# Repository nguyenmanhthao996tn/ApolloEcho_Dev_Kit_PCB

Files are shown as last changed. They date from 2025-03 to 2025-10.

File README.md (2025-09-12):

# ApolloEcho Dev Kit

This repository contains the PCB designs, related documents, and source code for the **ApolloEcho Dev Kit**.

The **ApolloEcho Dev Kit** includes two primary components: the **RAKwireless RAK11720** and the **EchoStar Mobile EM2050**. It is designed to provide a rapid and efficient approach to getting started with the EchoStar Mobile satellite network. All pinouts for the two modules are available in standard 2.54mm headers. The antenna is fully customizable via 6 SMA connectors.

## Rev 210 (Version 2.1.0)

### Changelog

- Change EM_RTS from PB12 to PA10
- Change J16 Pin 7 from PA10 to PB12
- Change J17 Pin 4 from PA10 to PB12
- Add 1 MOhm (R3) pull-down resistor for LDO_EM_PWR_EN

| Top View | Bottom View |
| :---: | :---: |
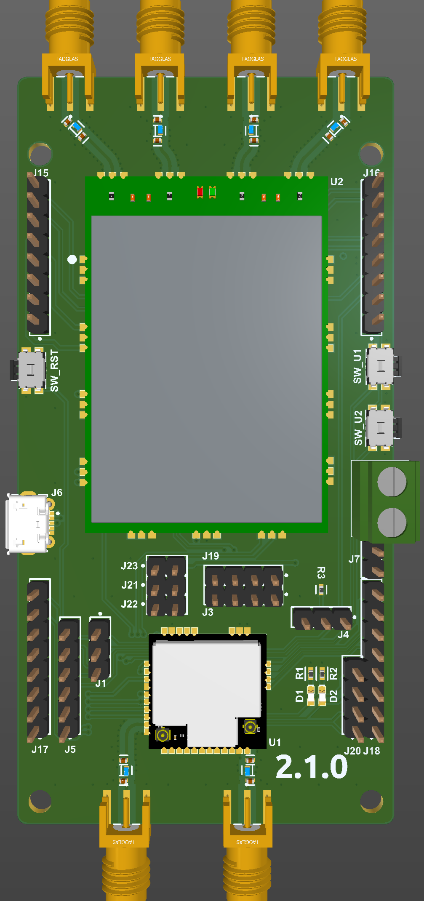
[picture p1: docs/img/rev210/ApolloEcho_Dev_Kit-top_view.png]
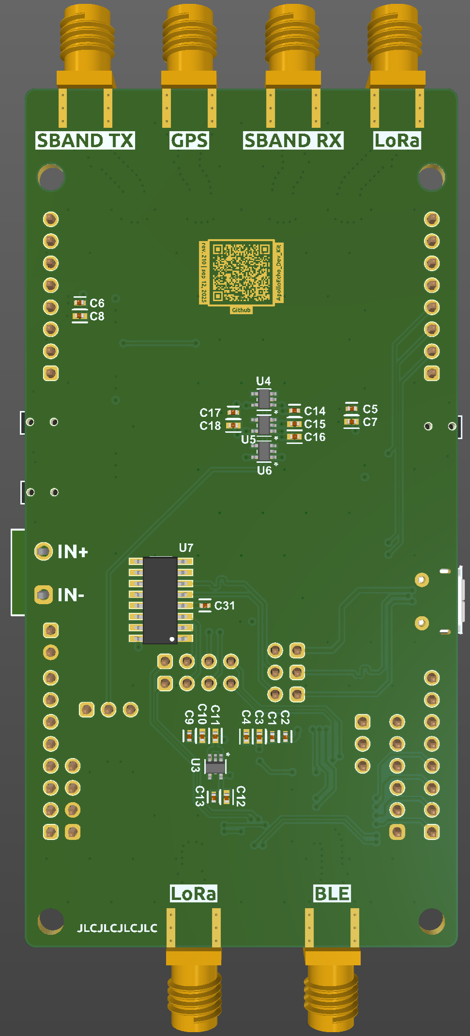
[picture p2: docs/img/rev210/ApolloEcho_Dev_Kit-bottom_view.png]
|  |  |

## Rev 200 (Version 2.0.0)

### Changelog

- Add integrated CH340C USB TTL IC
- Integrated USB TTL IC can interact with both RAK11720 and EM2050

| Top View | Bottom View |
| :---: | :---: |
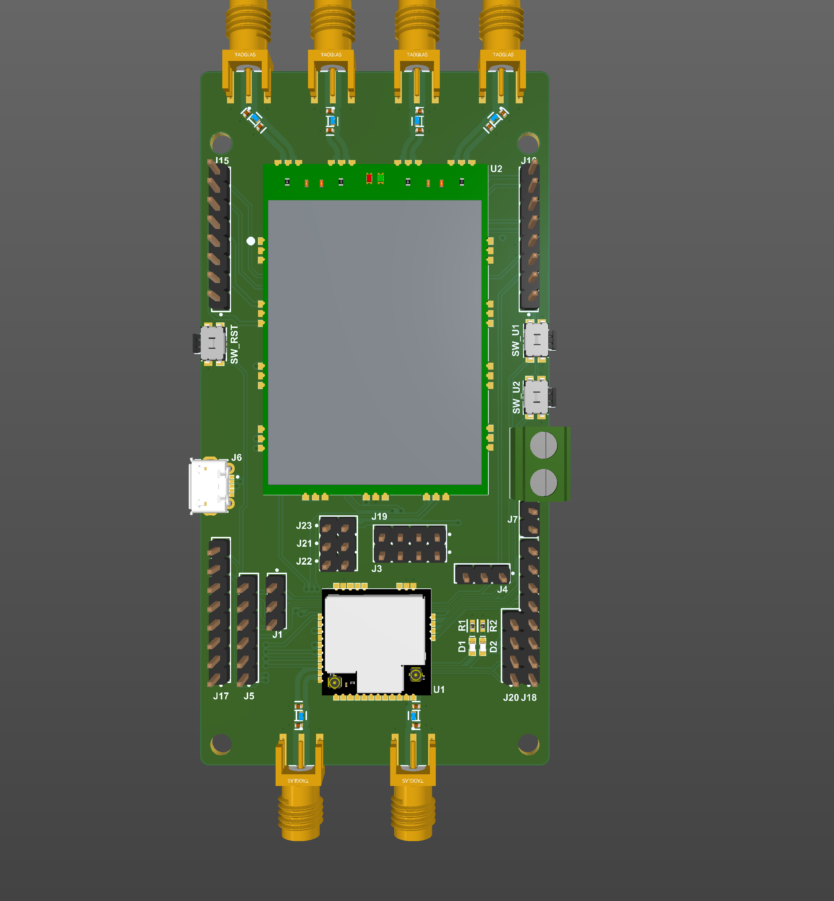
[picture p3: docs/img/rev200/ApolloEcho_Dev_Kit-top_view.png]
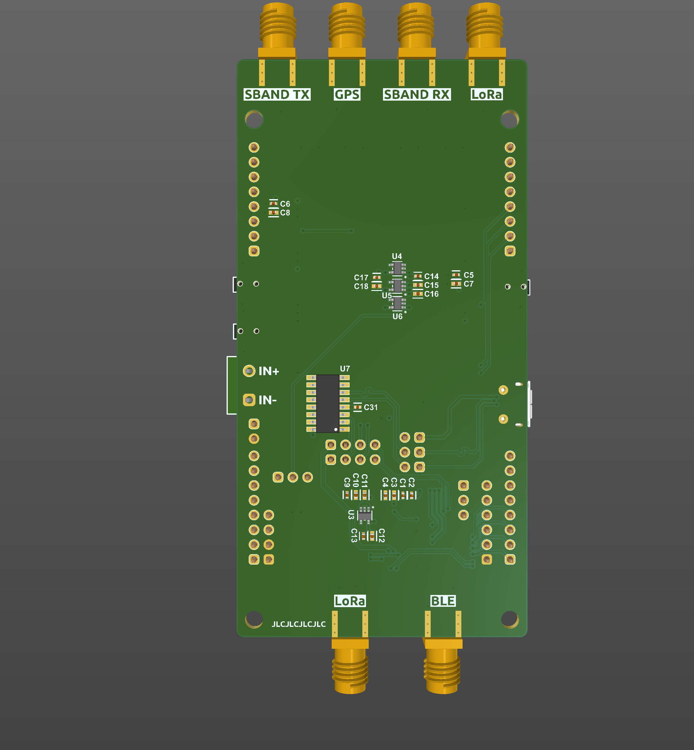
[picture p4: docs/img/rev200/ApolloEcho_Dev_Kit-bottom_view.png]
|  |  |

## Rev 100 (Version 1.0.0)

### Overview

The kit includes a separate CH340C on a USB Serial Daughter Board. For programming and debugging, the USB Serial Daughter Board provides a simple connection via Micro USB. For battery-powered deployments that require low power, removing the USB Serial Daughter Board can improve autonomy.

| Top View | Bottom View |
| :---: | :---: |
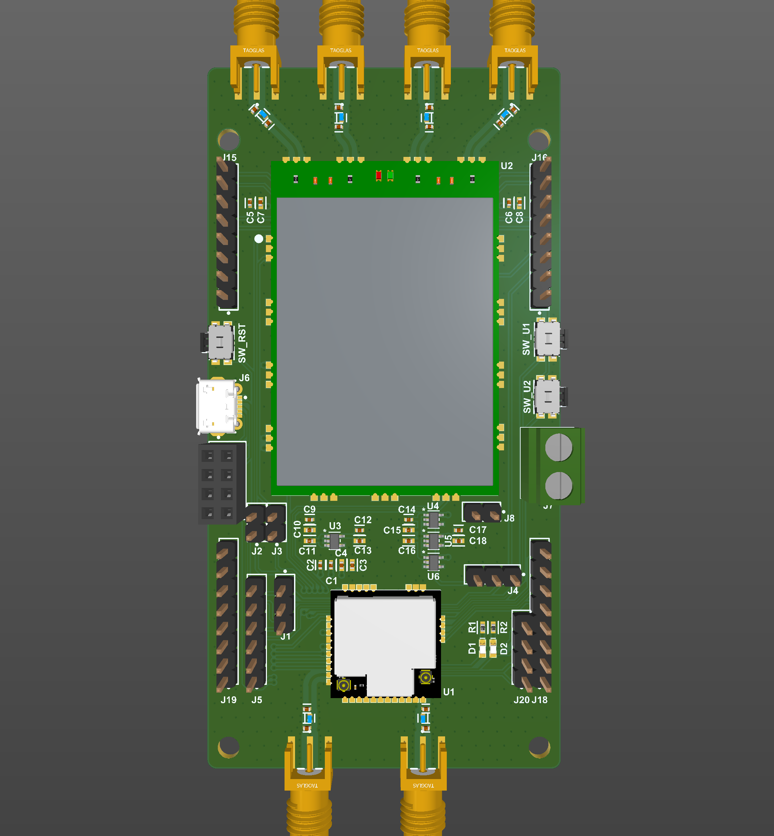
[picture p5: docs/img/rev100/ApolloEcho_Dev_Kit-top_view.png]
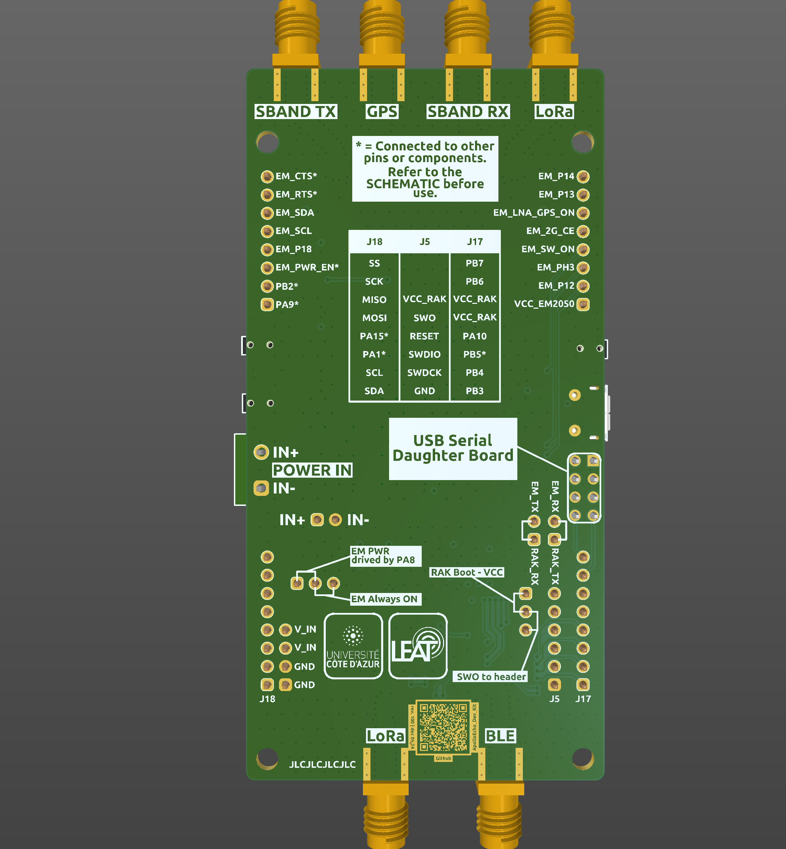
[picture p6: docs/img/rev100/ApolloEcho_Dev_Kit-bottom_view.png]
|  |  |

| Top View | Bottom View |
| :---: | :---: |
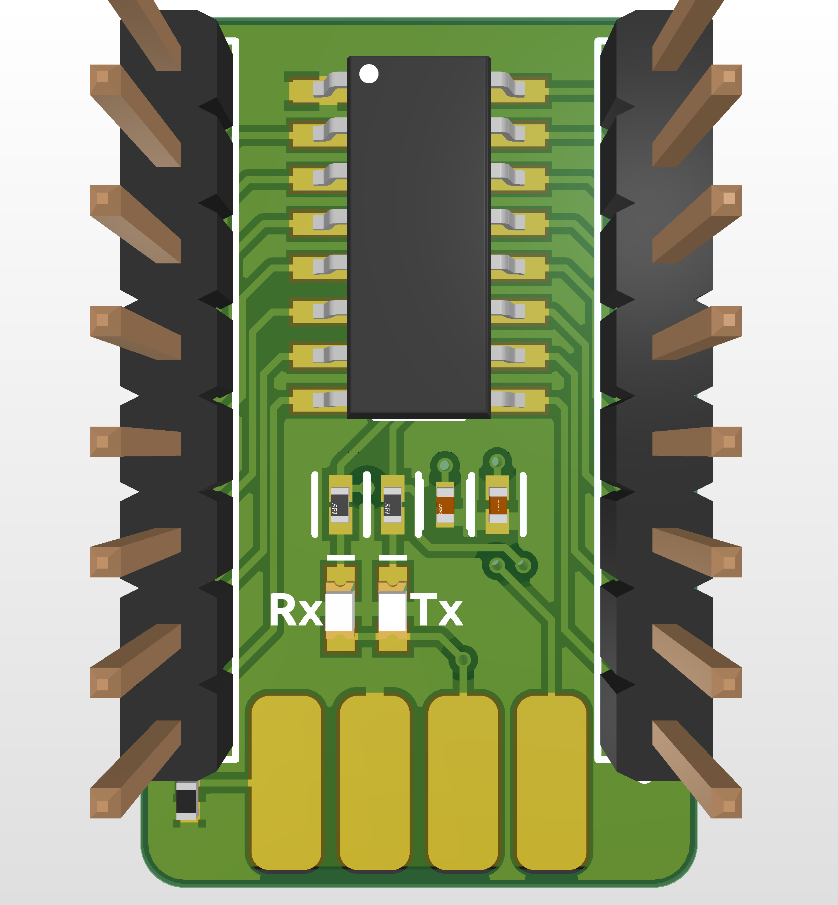
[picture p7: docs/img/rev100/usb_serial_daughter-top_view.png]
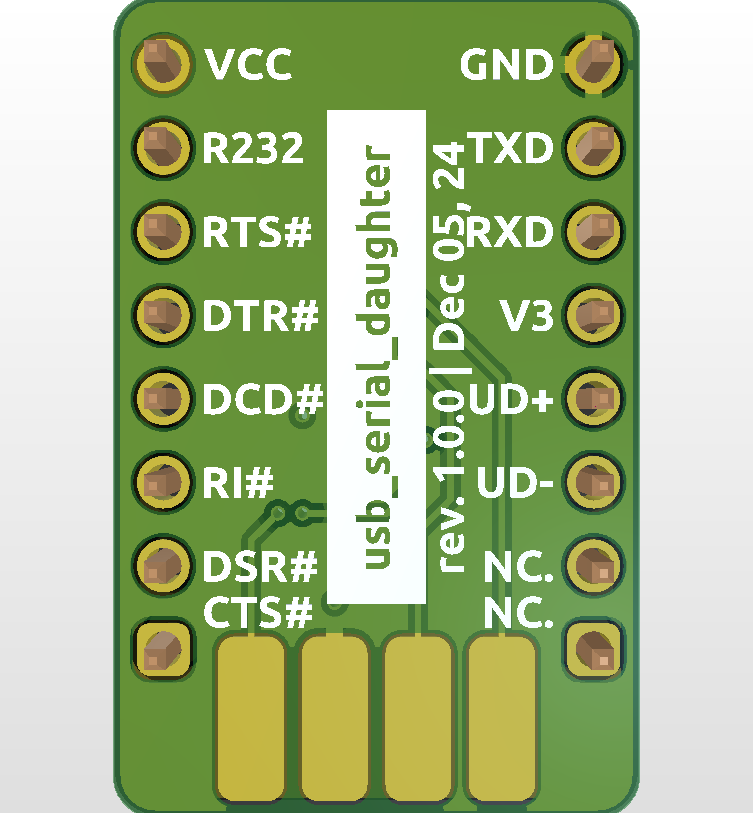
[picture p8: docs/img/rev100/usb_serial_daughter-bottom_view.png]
|  |  |

### Known issues

- The USBSerial Daughter board is not working.
- The SMA connectors are too close to each other.
- The QR code on the bottom is open in the paste layer. It's unscannable on the final board due to the soldering tin.

---

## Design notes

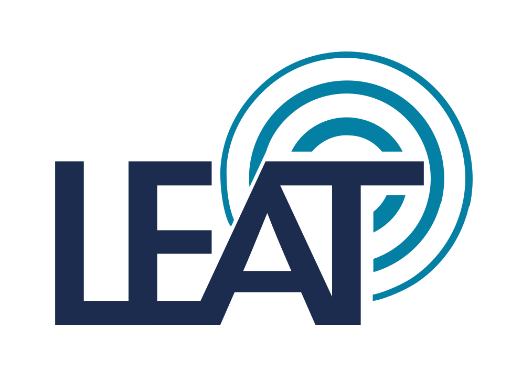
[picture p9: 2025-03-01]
docs/img/new-leat.png

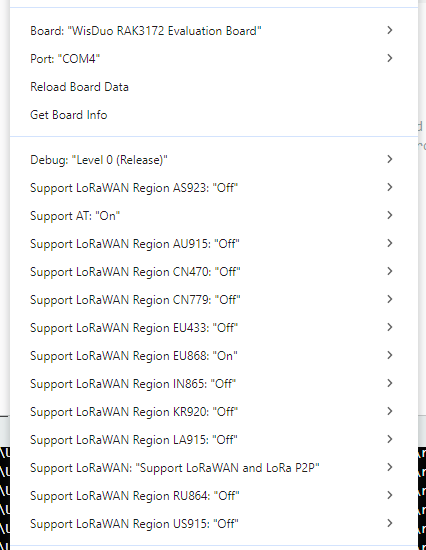
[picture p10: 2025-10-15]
docs/training_docs/arduino_rak3172_menu_config.png

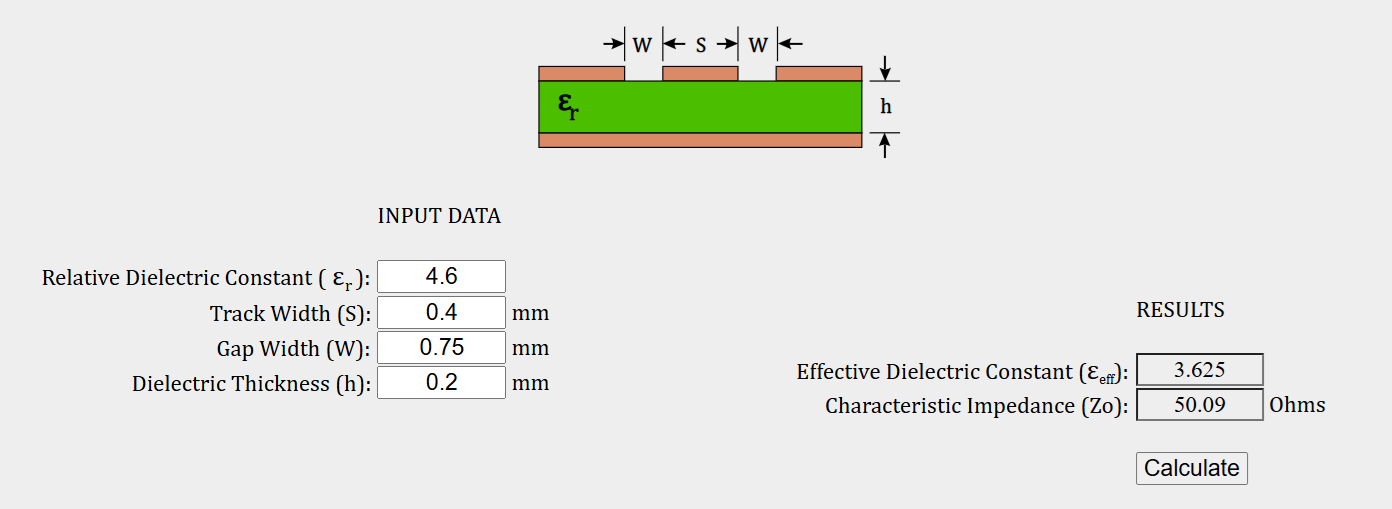
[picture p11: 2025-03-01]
docs/coplanar_matching.png

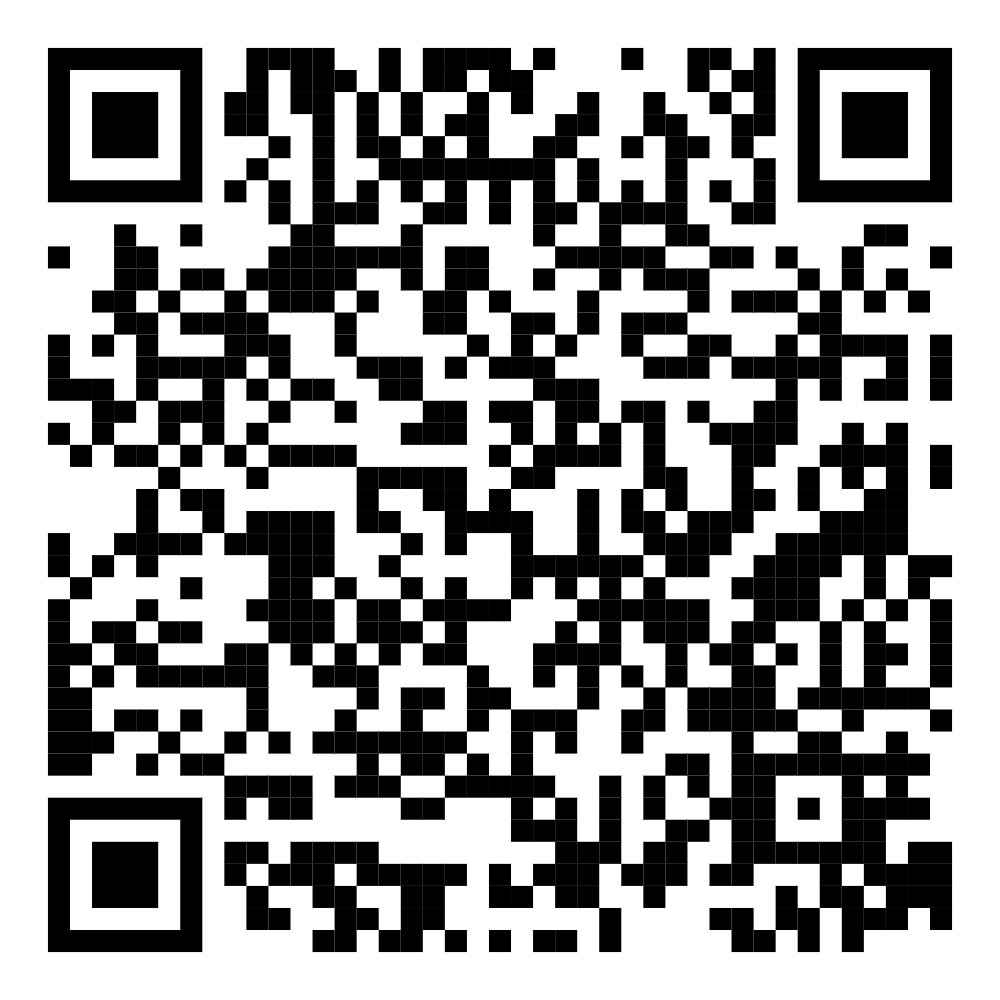
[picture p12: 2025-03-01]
docs/img/github.png

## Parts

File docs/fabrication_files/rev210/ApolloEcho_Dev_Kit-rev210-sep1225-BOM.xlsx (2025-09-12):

Comment | Description | Designator | Footprint | LibRef | Quantity | Value | Manufacture | Manufacturer | Manufacturer Packaging 1 | Manufacturer P/N | Manufacturer Part Number | Manufacturer URL
0402ZD104KAT2A | General Purpose Ceramic Capacitor, 0402, 100nF, 10%, X5R, 15%, 10V | C1, C2, C5, C6, C9, C12, C14, C17, C31 | FP-0402-L_1_0_1-W_0_5_0_1-IPC_C | CMP-2008-02878-3 | 9
EMK105BJ105KV-F | None | C3, C4, C7, C8, C10, C13, C15, C18 | FP-0402-L_1_0_0_05-W_0_5-IPC_A | CMP-14477-000104-2 | 8
C1005X5R1A225K050BC | Multilayer Ceramic Capacitors 2.2μF ±10% 10V X5R SMD 0402 | C11, C16 | FP-C1005-050-0_05-IPC_A | CMP-08246-002709-1 | 2
GJM1555C1H5R0CB01D | Multi-Layer Ceramic Capacitor 5pF C0G ±0.25pF 0402 Paper T/R | C19, C20, C21, C22, C23, C24, C25, C26, C27, C28, C29, C30 | FP-GJM155-0_05-MFG | CMP-2008-03860-2 | 12
150060VS75000 | WURTH ELEKTRONIK - 150060VS75000 - LED, Green, SMD, 0603, 30 mA, 2 V, 570 nm | D1 | WL-SMCW_0603_150060xx75000 | CMP-1426-00006-7 | 1
150060RS75000 | LED Low-Power Uni-Color Red 630nm 2V 2-Pin Chip 0603(1608Metric) T/R | D2 | WL-SMCW_0603_150060xx75000 | CMP-1426-00001-4 | 1
61300311121 |  | J1, J4 | 61300311121 | CMP-1502-01062-3 | 2
61300411121 |  | J3, J19, J20 | 61300411121 | CMP-1502-01064-3 | 3
61300611121 |  | J5 | 61300611121 | CMP-1502-01070-3 | 1
105017-0001 | Micro-USB B Receptacle, Right Angle, Bottom Mount, Surface Mount, with Solder Tabs, -30 to 85 degC, 5-Pin USB, RoHS, Tape and Reel | J6 | USB-MICRO-B_V | CMP-2000-05827-1 | 1 |  |  | Molex |  |  |  | http://www.molex.com/
691137710002 |  | J7 | 691137710002 | CMP-1502-03324-2 | 1
61300211121 |  | J8, J21, J22, J23 | 61300211121 | CMP-1712-00002-6 | 4
EMPCB.SMAFSTJ.B.HT | CONN SMA JACK STR 50OHM EDGE MNT | J9, J10, J11, J12, J13, J14 | FP-EMPCB_SMAFSTJ_B_HT-MFG | CMP-111093-000001-1 | 6 |  |  | Taoglas Limited |  |  | EMPCB.SMAFSTJ.B.HT
61300811121 |  | J15, J16, J17, J18 | 61300811121 | CMP-1502-01076-3 | 4
LQW15AN2N9D00D | Wire Wound RF Inductor 2.9nH ±0.5nH 750mA 0.07Ω 0402 (1005) | L1, L2, L3, L4, L5, L6 | FP-LQW15AN_00-W0_6-0_1-MFG | CMP-06042-011289-1 | 6
RMCF0402FT1K00 | 1kΩ ±1% 0.063W 0402 Thick Film Chip Resistor AEC-Q200 compliant | R1, R2 | FP-RMCF0402-IPC_A | CMP-26527-000026-1 | 2
RMCF0402FT1M00 | 1MΩ ±1% 0.063W 0402 Thick Film Chip Resistor AEC-Q200 compliant | R3 | FP-RMCF0402-MFG | CMP-2000-06985-2 | 1
436333045822 |  | SW_RST, SW_U1, SW_U2 | 436333045822 | CMP-1464-00001-2 | 3
RAK11720 | RAK11720 Ambiq Apollo3 Blue SX1262 LoRa Bluetooth Module for LoRaWAN | U1 | RAK11720 | RAK11720 | 1
IOT SAT module | Echostar Mobile IOT SAT Module - Basic version | U2 | EM2050 | EM2050 | 1 | EM2050 |  | Echostar Mobile Ltd |  | EM2050
STLQ020C33R | No Description Available | U3, U4, U5, U6 | SOT323-5L_STM | STLQ020C33R | 4
CH340C | USB to Serial CH340 IC | U7 | CH340C | CH340C | 1

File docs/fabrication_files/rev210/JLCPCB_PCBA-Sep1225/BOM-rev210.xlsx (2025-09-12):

Comment | Designator | Footprint | JLCPCB Part #（optional）
16V 100nF X7R ±10% 0402 Multilayer Ceramic Capacitors MLCC - SMD/SMT ROHS | C1, C2, C5, C6, C9, C12, C14, C17, C31 | 0402 | C1525
25V 1uF X5R ±10% 0402 Multilayer Ceramic Capacitors MLCC - SMD/SMT ROHS | C3, C4, C7, C8, C10, C13, C15, C18 | 0402 | C52923
6.3V 2.2uF X5R ±20% 0402 Multilayer Ceramic Capacitors MLCC - SMD/SMT ROHS | C11, C16 | 0402 | C12530
-40℃~+85℃ Red 0603 LED Indication - Discrete ROHS | D1 | 0603 | C2286
White 0603 LED Indication - Discrete ROHS | D2 | 0603 | C2290
62.5mW Thick Film Resistors 50V ±1% 0Ω 0402 Chip Resistor - Surface Mount ROHS | L1, L2, L3, L4, L5, L6 | 0402 | C17168
62.5mW Thick Film Resistors 50V ±100ppm/℃ ±1% 1kΩ 0402 Chip Resistor - Surface Mount ROHS | R1, R2 | 0402 | C11702
62.5mW Thick Film Resistors 50V ±100ppm/℃ ±1% 1MΩ 0402 Chip Resistor - Surface Mount ROHS | R3 | 0402 | C26083
3.2mm 2.5mm Oval button 50mA Standing paste 4.2mm SPST 16V SMD Tactile Switches ROHS | SW_RST, SW_U1, SW_U2 | SMD | C115360
LDO Voltage Regulators 200 mA ultra-low quiescent current LDO | U3, U4, U5, U6 | SOT-323-5 | C2970558
SOP-16 USB Converters ROHS | U7 | SOP-16 | C7464026
1 Inner Hole SMA Board-End Staggered pins 50Ω 5.2mm SMD Coaxial Connectors (RF) ROHS | J9, J10, J11, J12, J13, J14 | SMD | C496550
1.8A USB 2.0 1 Horizontal attachment 5P Female -20℃~+85℃ Micro-B SMD USB Connectors ROHS | J6 | SMD | C404969
1x2P -40℃~+105℃ 12A 300V Green 14~26 Direct Insert 5.08mm 1 2 P=5.08mm Screw Terminal Blocks ROHS | J7 | P=5.08mm | C3018698

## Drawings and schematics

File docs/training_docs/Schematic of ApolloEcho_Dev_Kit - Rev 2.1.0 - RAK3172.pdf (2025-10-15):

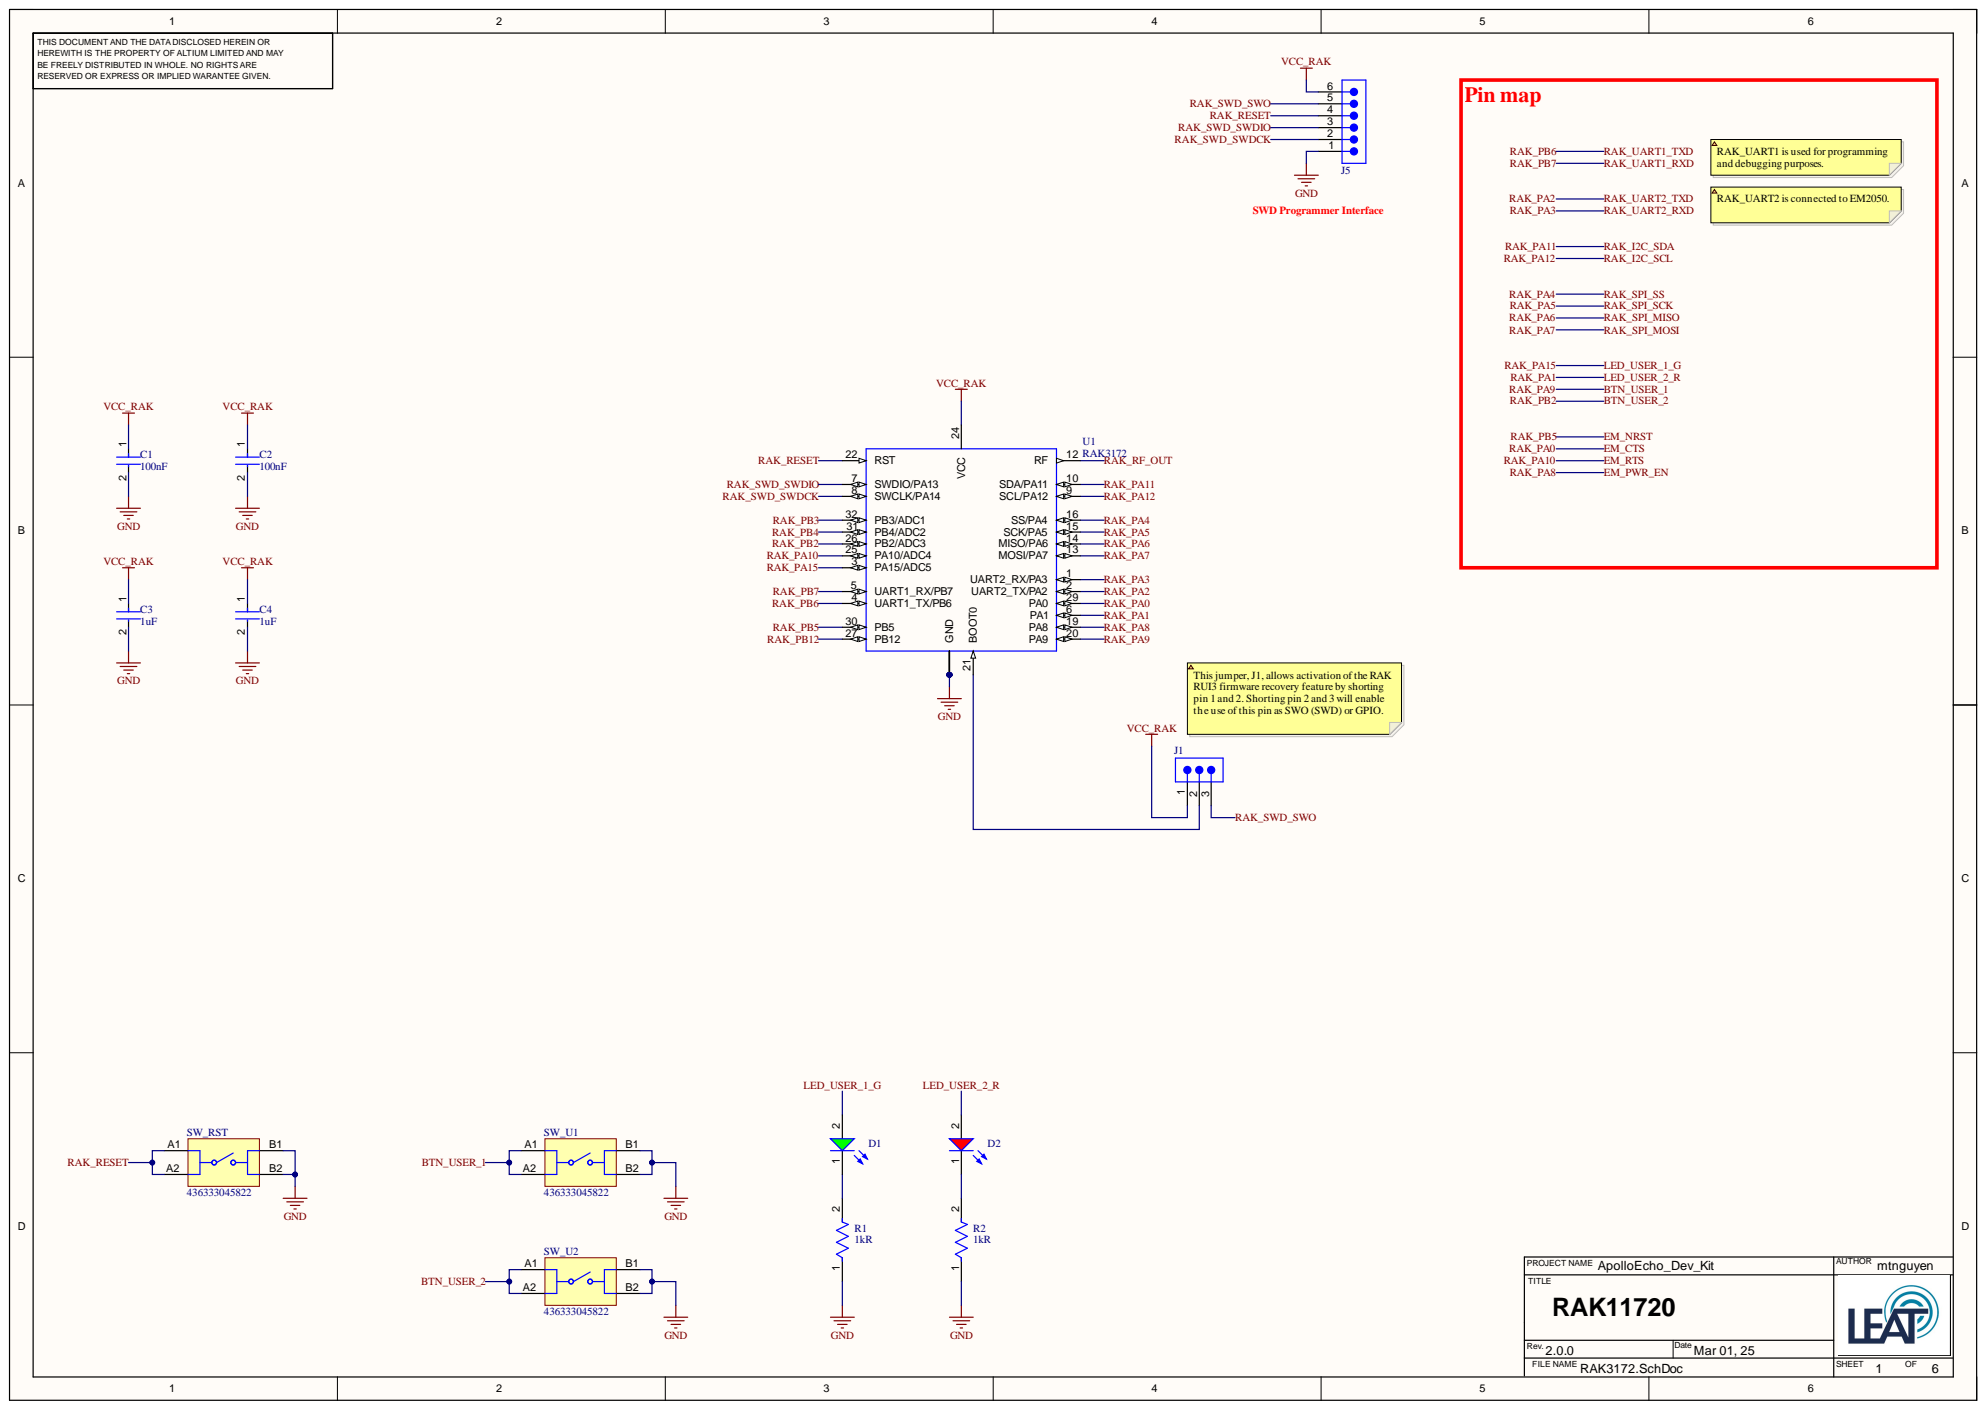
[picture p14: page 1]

THIS DOCUMENT AND THE DATA DISCLOSED HEREIN OR
HEREWITH IS THE PROPERTY OF ALTIUM LIMITED AND MAY
BE FREELY DISTRIBUTED IN WHOLE. NO RIGHTS ARE
RESERVED OR EXPRESS OR IMPLIED WARANTEE GIVEN.

RAK_UART1 is used for programming
and debugging purposes.

This jumper, J1, allows activation of the RAK
RUI3 firmware recovery feature by shorting
pin 1 and 2. Shorting pin 2 and 3 will enable
the use of this pin as SWO (SWD) or GPIO.

Rev. 2.0.0 | Date Mar 01, 25
FILE NAME RAK3172.SchDoc | SHEET OF 1

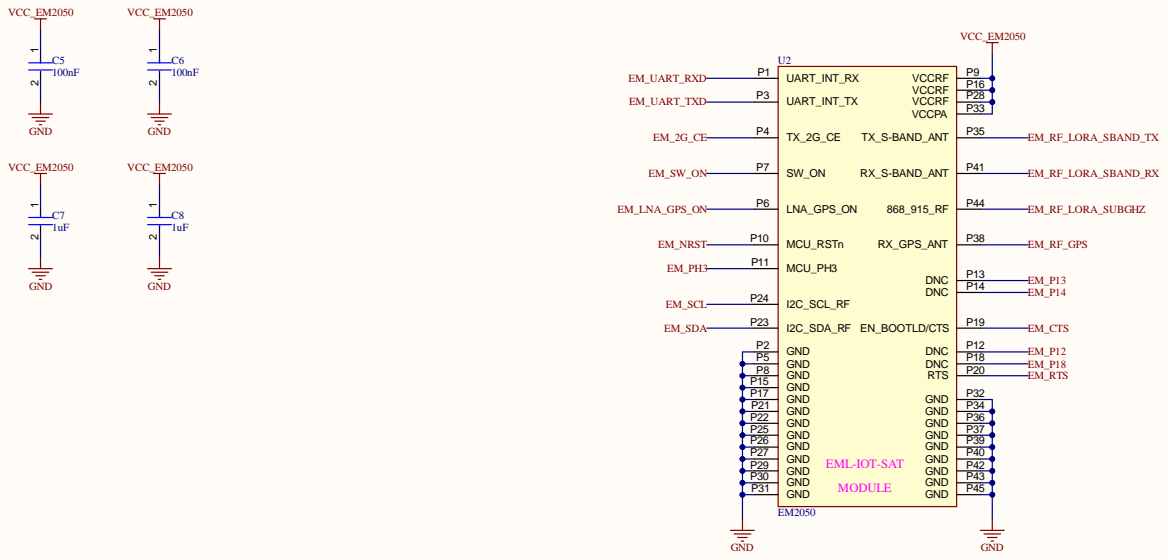
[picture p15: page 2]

AND THE DATA DISCLOS
ENT

PROJECT NA M E | AUTHOR ApolloEcho_Dev_Kit e n
TIT L E EM2050 | T OF mtnguy

Re v . 2.0 . 0 | Date M ar 1,
FIL E NA M E EM 0.Sc h D o c | SHE E

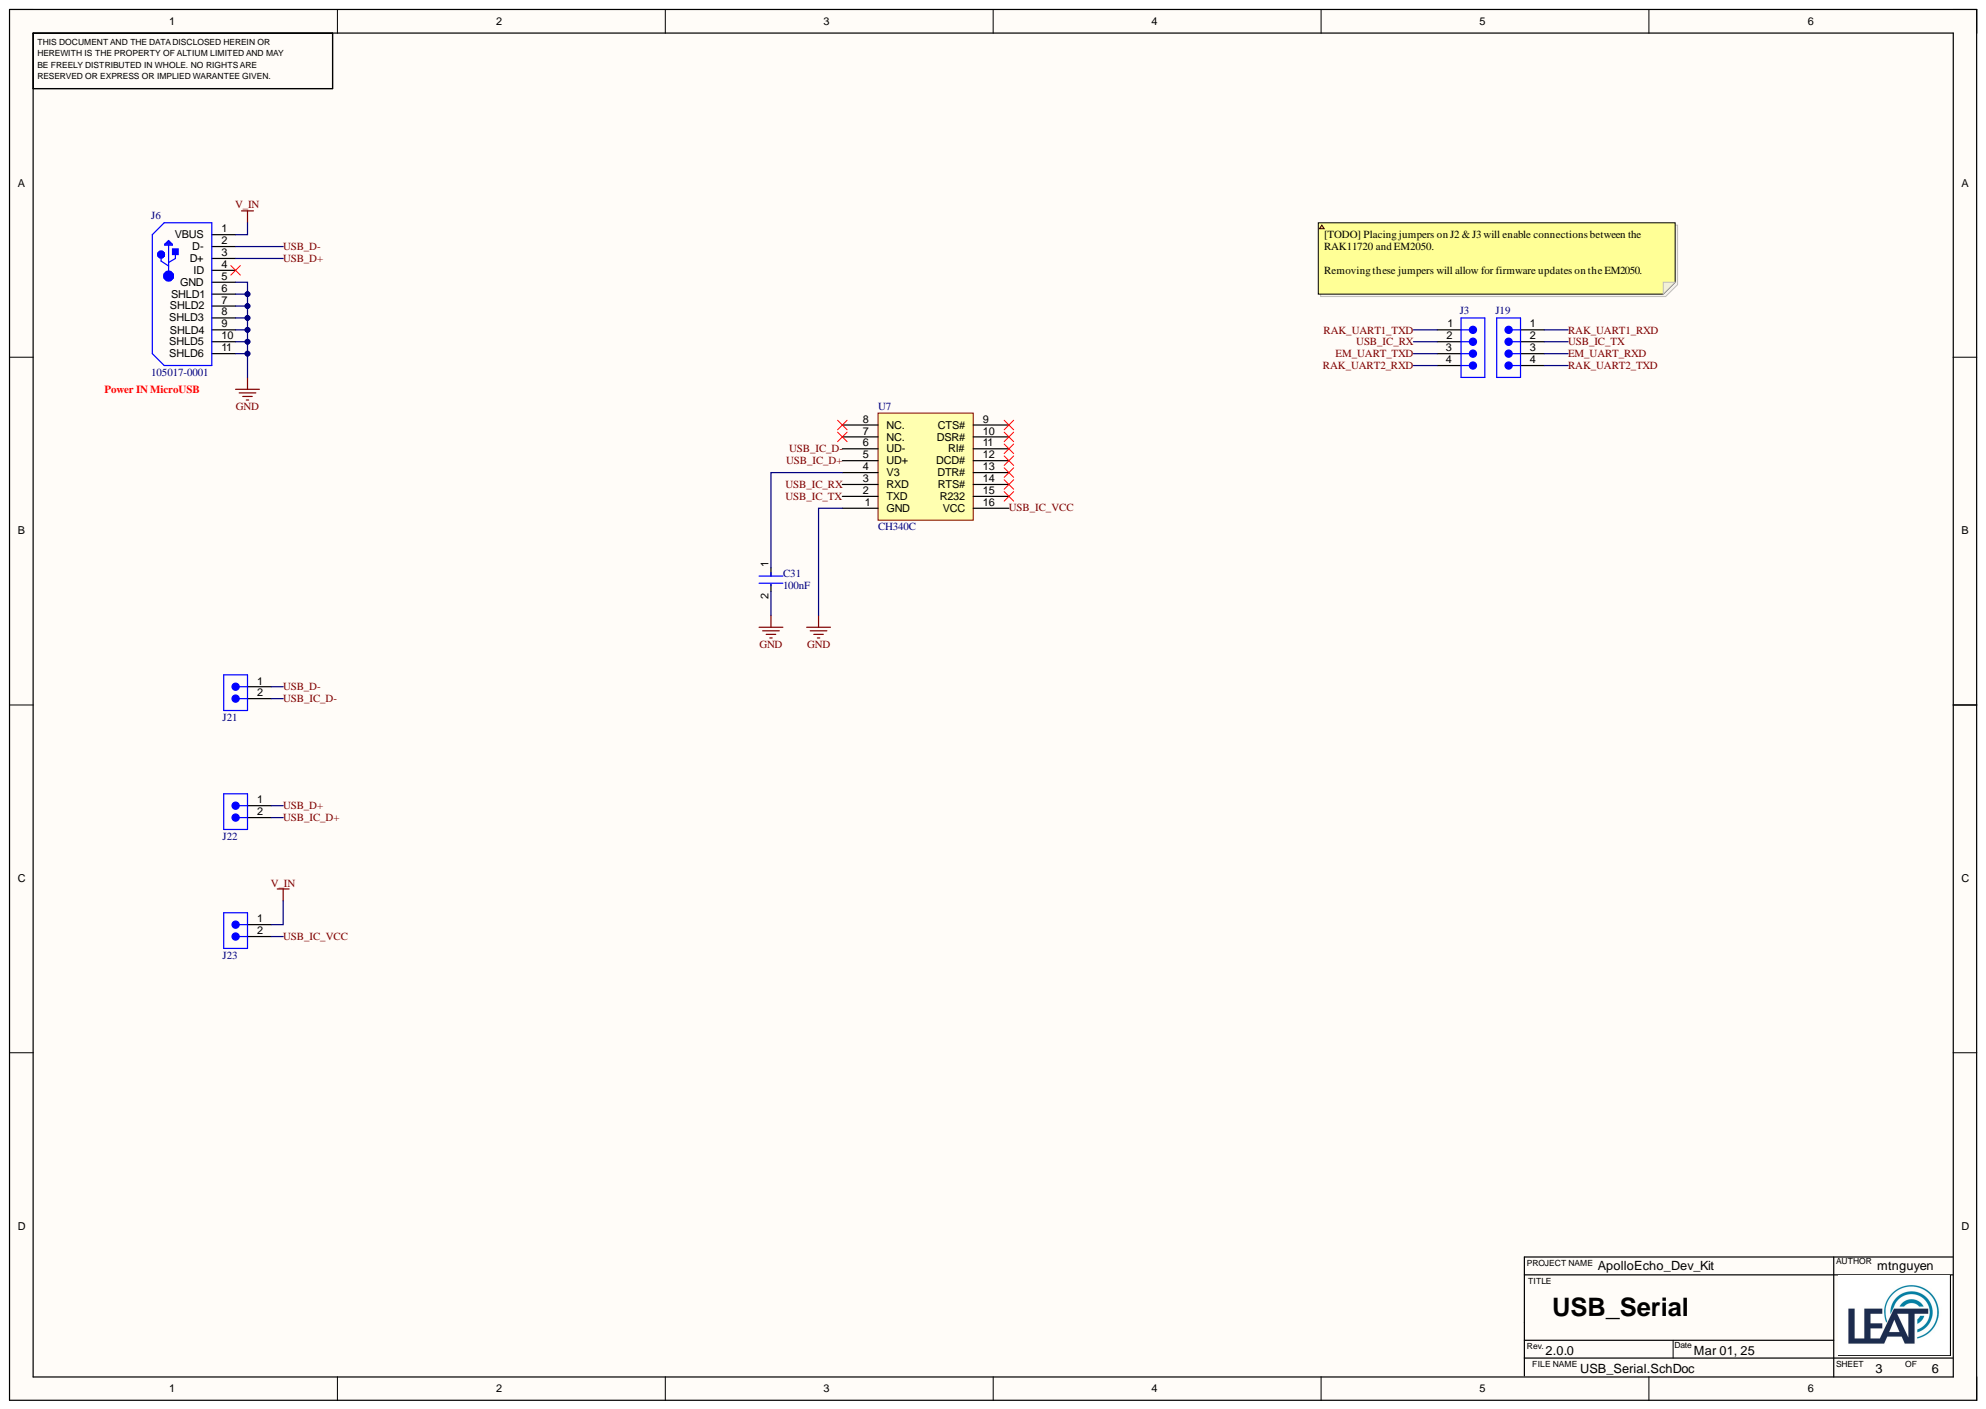
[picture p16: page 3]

RESERVED OR EXPRESS OR IMPLIED WARANTEE GIVEN.

[TODO] Placing jumpers on J2 & J3 will enable connections between the
RAK11720 and EM2050.

Removing these jumpers will allow for firmware updates on the EM2050.

AUTHOR ApolloEcho_Dev_Kit mtnguyen PROJECT NAME
TITLE USB_Serial

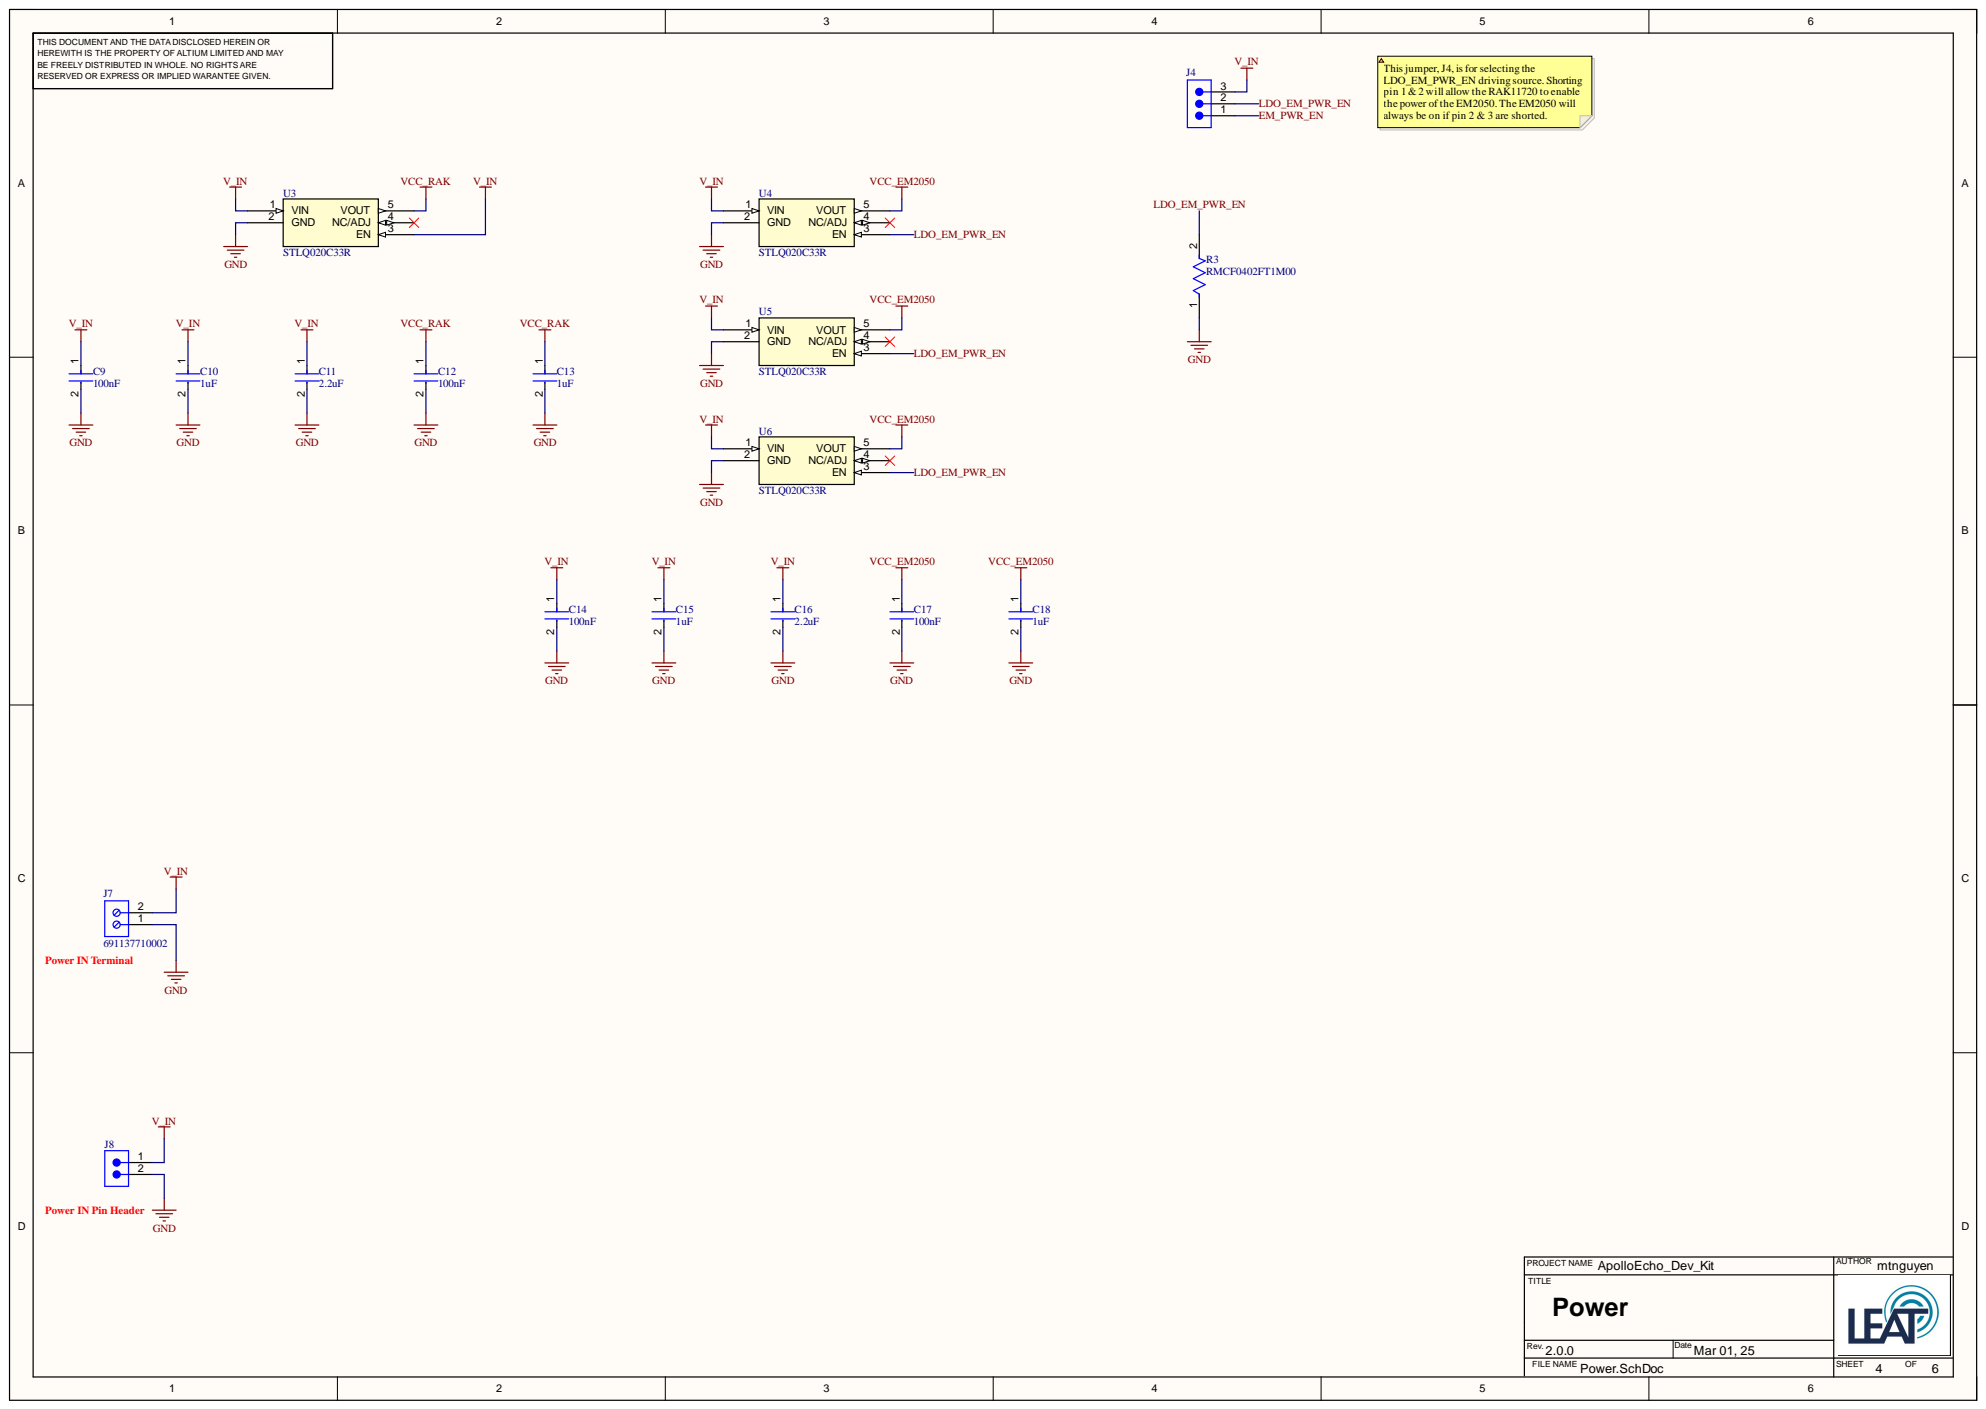
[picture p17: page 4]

This jumper, J4, is for selecting the
LDO_EM_PWR_EN driving source. Shorting
pin 1 & 2 will allow the RAK11720 to enable
the power of the EM2050. The EM2050 will
always be on if pin 2 & 3 are shorted.

RESERVED OR EXPRESS OR IMPLIED WARANTEE GIVEN.

Power IN Pin Header

AUTHOR ApolloEcho_Dev_Kit mtnguyen PROJECT NAME
TITLE Power

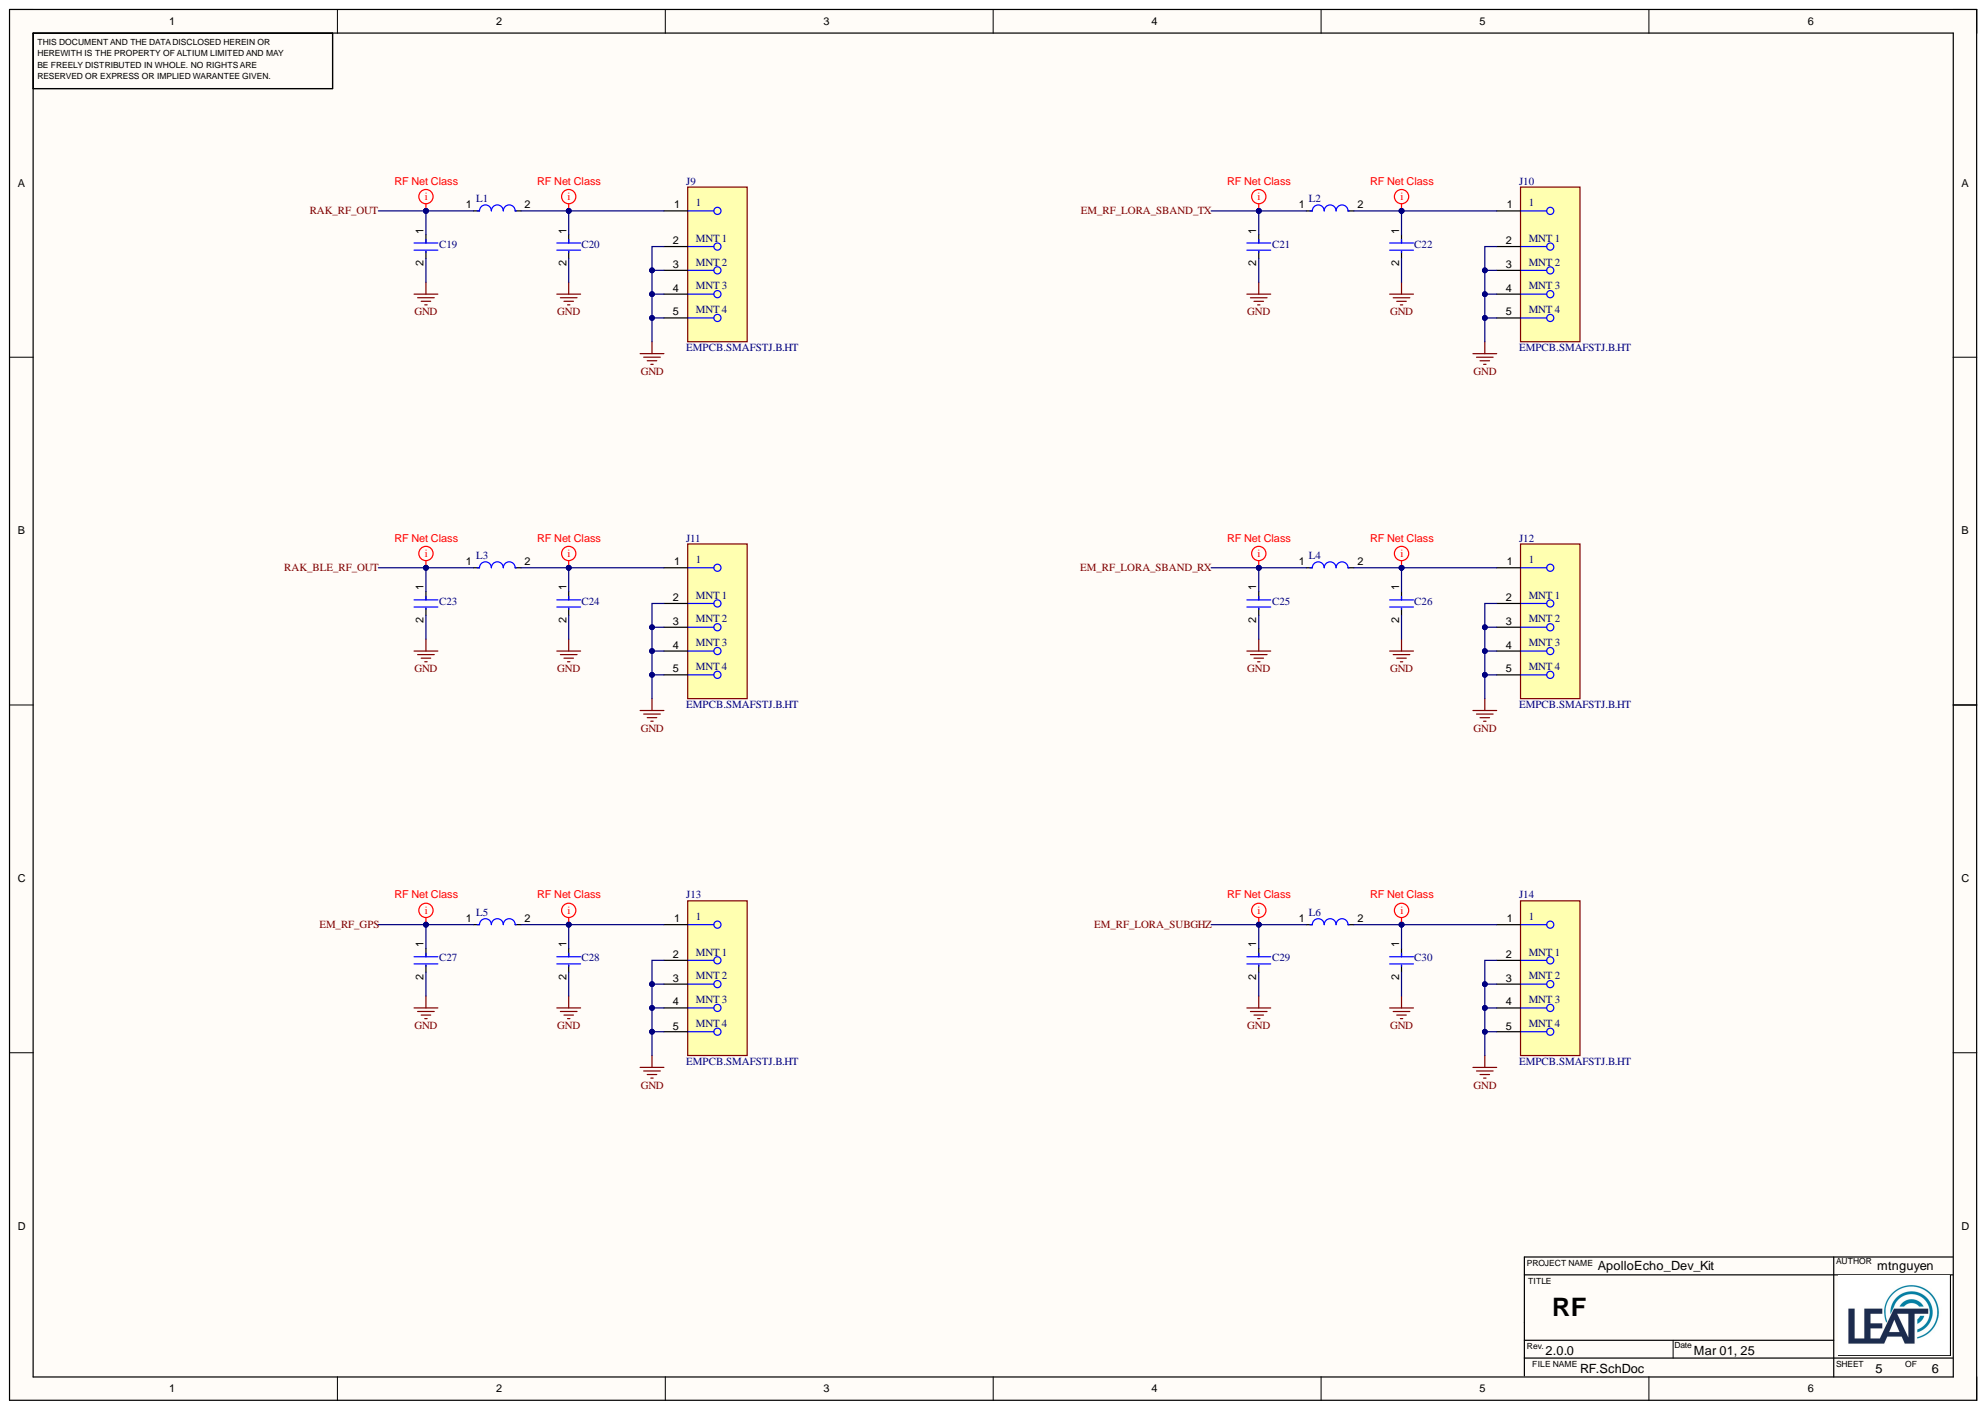
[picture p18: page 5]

RESERVED OR EXPRESS OR IMPLIED WARANTEE GIVEN.

AUTHOR ApolloEcho_Dev_Kit mtnguyen PROJECT NAME
TITLE RF

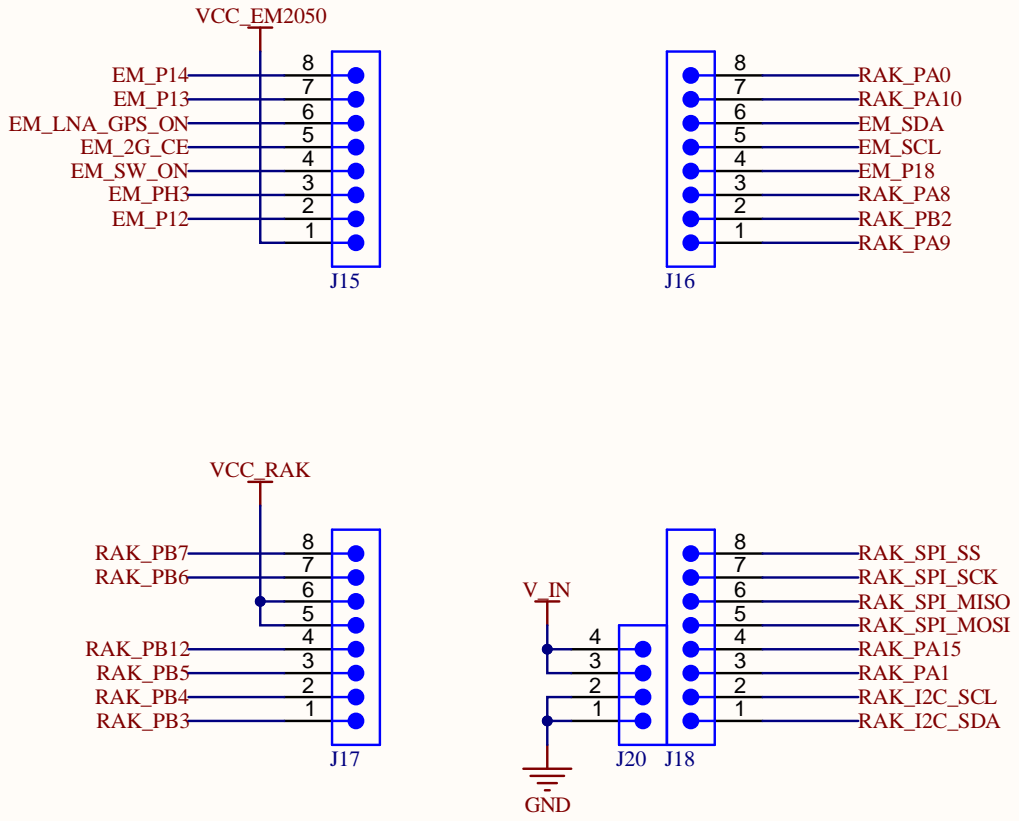
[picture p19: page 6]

RESERVED OR EXPRESS OR IMPLIED WARANTEE GIVEN.

AUTHOR ApolloEcho_Dev_Kit mtnguyen PROJECT NAME
TITLE IOs

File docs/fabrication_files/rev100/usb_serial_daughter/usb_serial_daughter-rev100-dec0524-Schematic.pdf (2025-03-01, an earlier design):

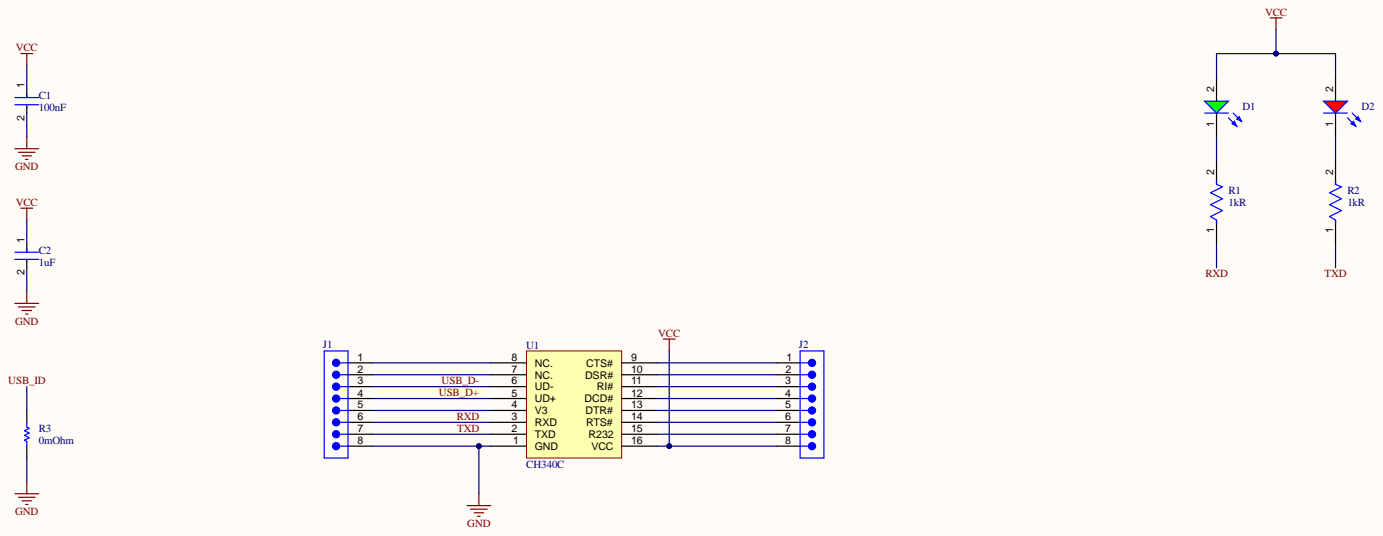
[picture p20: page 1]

WITH IS THE PROP
LY DISTRIBUTED IN WHOL

USB_ D + | 1 2

RX D | 1 4
TX D | 1 5

PROJECT NA M E | AUTHOR ApolloEcho_Dev_Kit mtnguyen
TITL E USB Serial

Re v . 1.0.0 | Da t e Dec 03, 24
FIL E NA M E usb_serial_daughter.SchDoc | SHE E T OF 1 1

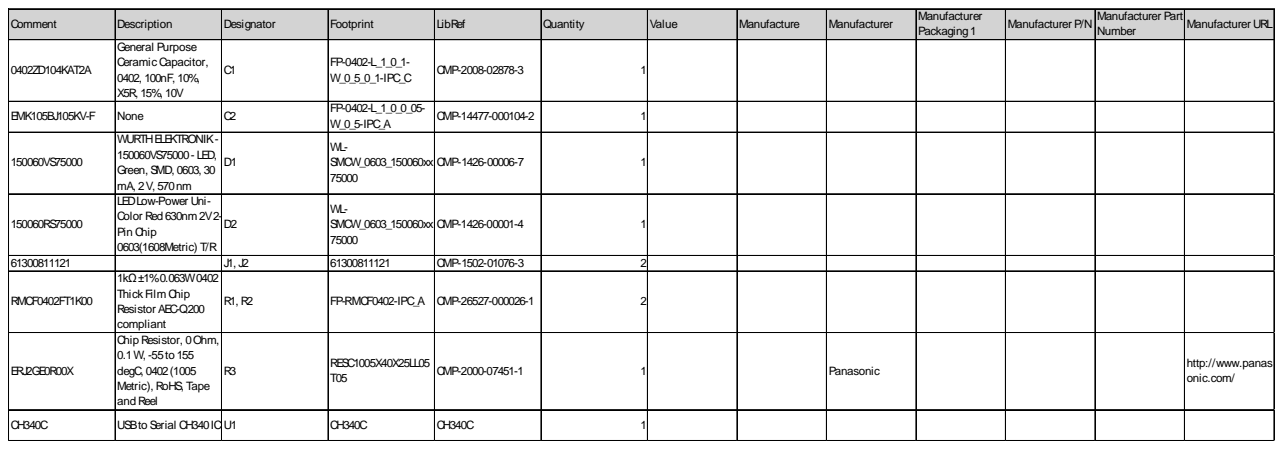
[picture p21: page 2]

Comment | Description | Designator | Footprint | LibRef | Quantity | Value | Manufacture | Manufacturer | Manufacturer Packaging1 | Manufacturer P/N | Manufacturer Part Number | Manufacturer URL

0402ZD104KAT2A | General Purpose Ceramic Capacitor, 0402, 100nF, 10%, X5R, 15%, 10V | C1 | FP-0402-L_1_0_1-W_0_5_0_1-IPC_C | CMP-2008-02878-3 | 1

EMK105BJ105KV-F | None | C2 | FP-0402-L_1_0_0_05-W_0_5-IPC_A | CMP-14477-000104-2 | 1

150060VS75000 | WURTHELEKTRONIK-150060VS75000- LED, Green, SMD, 0603, 30 mA, 2V, 570nm | D1 | WL-SMCW_0603_150060xx 75000 | CMP-1426-00006-7 | 1

150060RS75000 | LEDLow-Power Uni-Color Red 630nm 2V2-Pin Chip 0603(1608Metric) T/R | D2 | WL-SMCW_0603_150060xx 75000 | CMP-1426-00001-4 | 1

61300811121 | | J1, J2 | 61300811121 | CMP-1502-01076-3 | 2
RMCF0402FT1K00 | 1kΩ±1%0.063W0402 Thick Film Chip Resistor AEC-Q200 compliant | R1, R2 | FP-RMCF0402-IPC_A | CMP-26527-000026-1 | 2

ERJ2GE0R00X | Chip Resistor, 0Ohm, 0.1W, -55to 155 degC, 0402(1005 Metric), RoHS, Tape and Reel | R3 | RESC1005X40X25LL05 T05 | CMP-2000-07451-1 | 1 | | | Panasonic | | | | http://www.panasonic.com/

CH340C | USBto Serial CH340ICU1 | | CH340C | CH340C | 1

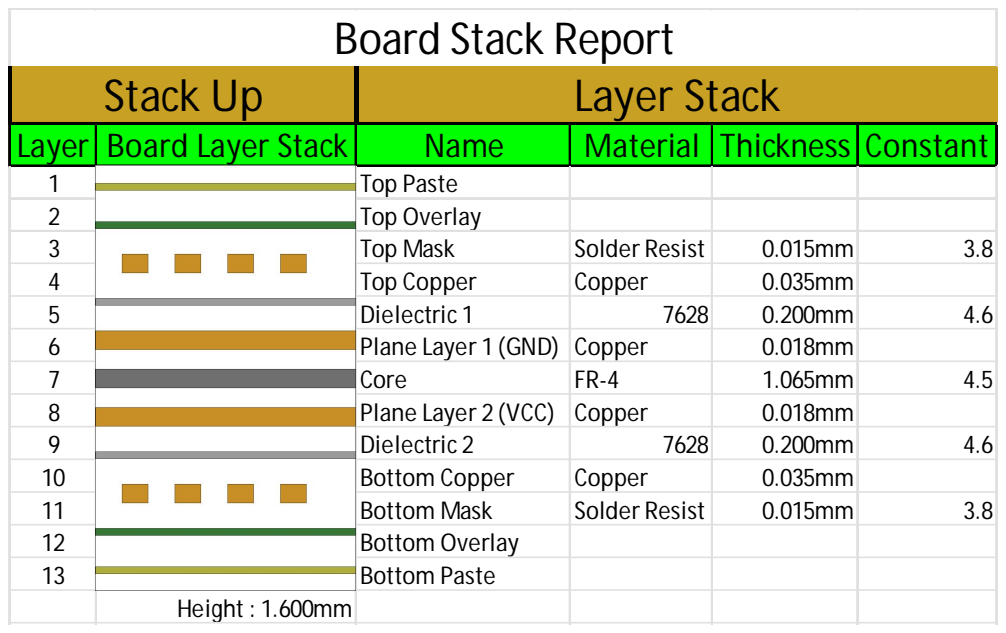
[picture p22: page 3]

Stack Up | Layer Stack
Layer | Board Layer Stack | Name | Material | Thickness Constant
1 | | Top Paste
2 | | Top Overlay

12 | | Bottom Overlay
13 | | Bottom Paste

Height : 1.600mm

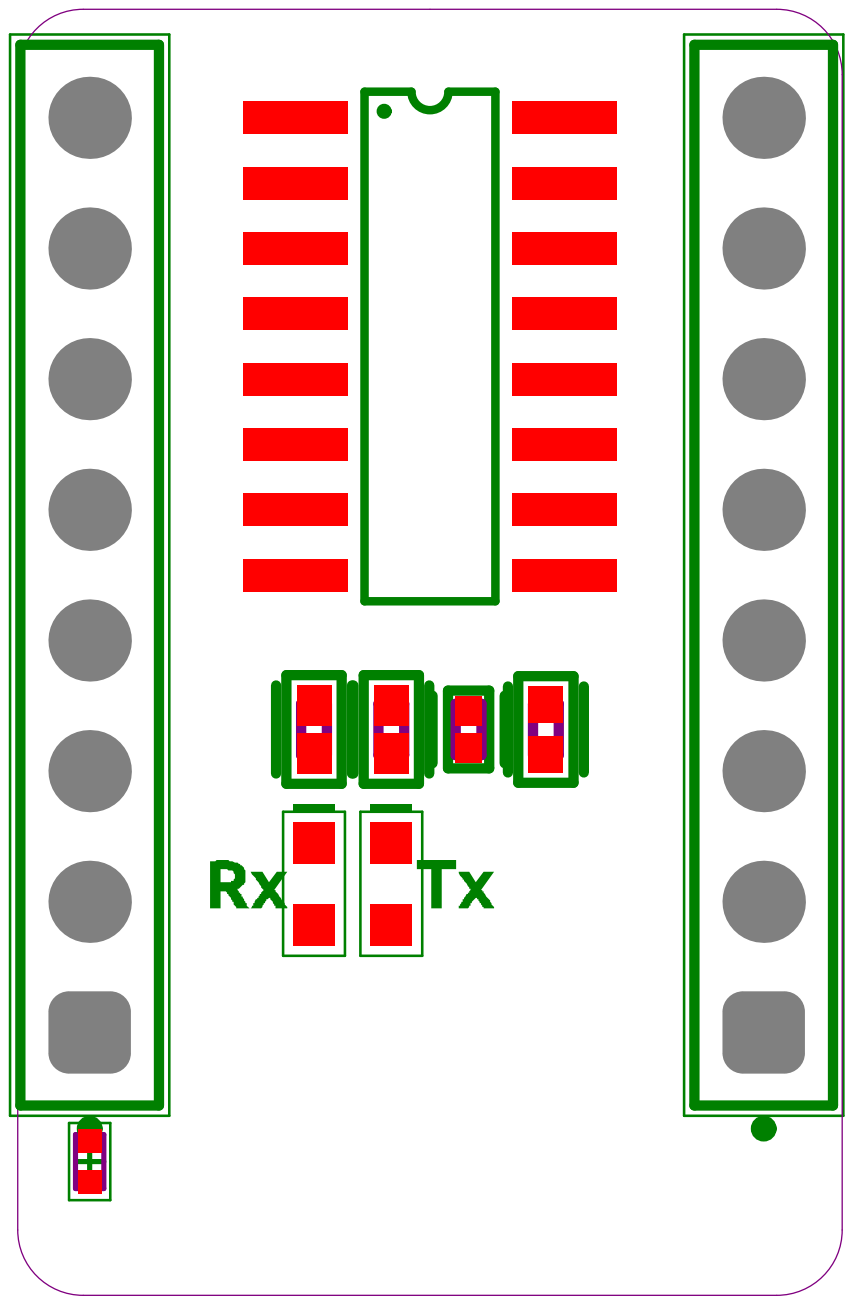
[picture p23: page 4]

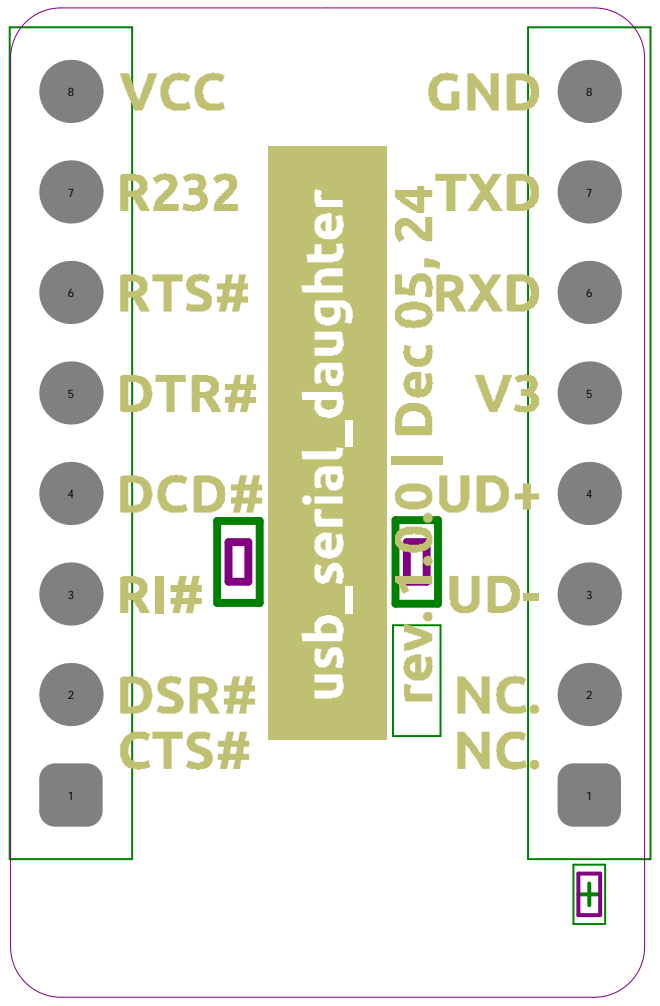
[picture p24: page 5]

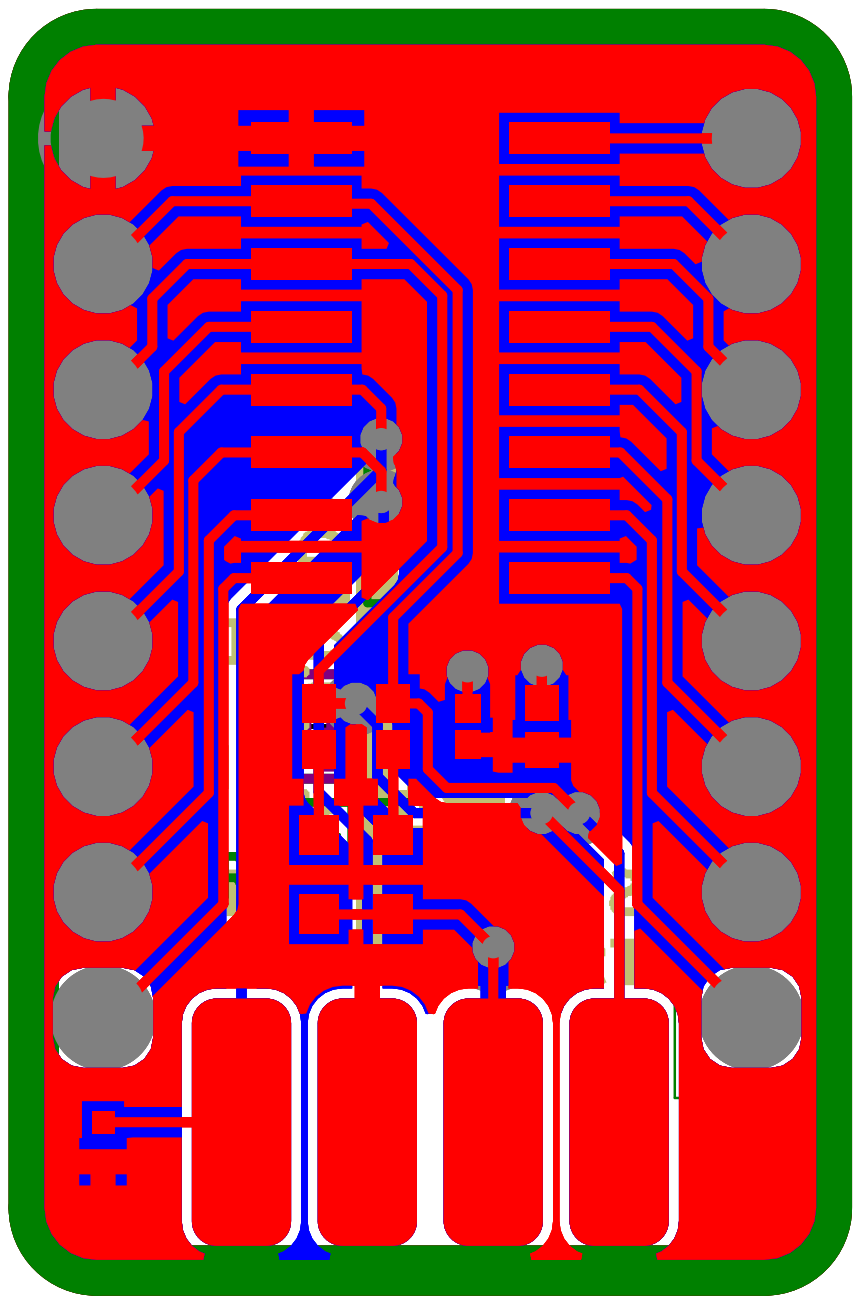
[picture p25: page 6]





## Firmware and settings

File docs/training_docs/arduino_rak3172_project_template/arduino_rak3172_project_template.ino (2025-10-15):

/**
 * @brief This is a template project for ApolloEcho Dev Kit rev2.1.0 with RAK3172.
 * 
 * This code is compiled with Arduino IDE using RAK RUI3 core.
 * Arduino IDE and RAK RUI3 installation guide: https://docs.rakwireless.com/product-categories/software-apis-and-libraries/rui3/supported-ide/#arduino-ide
 * 
 */

// ===== PIN DEFINITIONS =====
#define ECHOSTAR_nRST_PIN PB5
#define ECHOSTAR_BOOT_PIN PA0
#define ECHOSTAR_RTS_PIN PA10
#define ECHOSTAR_PWR_ENABLE_PIN PA8

#define LED_USER_1_G PA15  // Red LED on actual board
#define LED_USER_2_R PA1  // White LED on actual board
#define BTN_USER_1 PA9
#define BTN_USER_2 PB2
// ===========================


// ===== MAIN =====
void setup(void) {
  gpio_init();
  EM2050_reset_to_run();

  // Your setup code here
}

void loop(void) {
  // Your main code here
}
// =================


// ===== USER FUNCTIONS =====
void gpio_init(void) {
  // LEDs
  pinMode(LED_USER_1_G, OUTPUT);
  digitalWrite(LED_USER_1_G, LOW);

  pinMode(LED_USER_2_R, OUTPUT);
  digitalWrite(LED_USER_2_R, LOW);

  // Buttons
  pinMode(BTN_USER_1, INPUT_PULLUP);
  pinMode(BTN_USER_2, INPUT_PULLUP);

  // EM2050 Control Pins
  pinMode(ECHOSTAR_PWR_ENABLE_PIN, OUTPUT);
  digitalWrite(ECHOSTAR_PWR_ENABLE_PIN, HIGH);

  pinMode(ECHOSTAR_RTS_PIN, OUTPUT);
  digitalWrite(ECHOSTAR_RTS_PIN, LOW);
  
  pinMode(ECHOSTAR_nRST_PIN, OUTPUT);
  pinMode(ECHOSTAR_BOOT_PIN, OUTPUT);
  EM2050_reset_to_run();
}

void EM2050_reset_to_bootloader(void) {
  digitalWrite(ECHOSTAR_nRST_PIN, LOW);
  digitalWrite(ECHOSTAR_BOOT_PIN, LOW);
  delay(200);
  digitalWrite(ECHOSTAR_nRST_PIN, HIGH);
}

void EM2050_reset_to_run(void) {
  digitalWrite(ECHOSTAR_nRST_PIN, LOW);
  digitalWrite(ECHOSTAR_BOOT_PIN, HIGH);
  delay(200);
  digitalWrite(ECHOSTAR_nRST_PIN, HIGH);
}
// ===========================

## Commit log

2025-03-01 Push local development
    [ApolloEcho_Dev_Kit-rev100-dec0524-BOM.xlsx, ApolloEcho_Dev_Kit-rev100-dec0524-PickNPlace.csv, ApolloEcho_Dev_Kit.PrjPcb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]
2025-03-01 Add: Images for PCBs rev100
2025-03-02 Add rev200
    [ApolloEcho_Dev_Kit-rev200-mar0225-BOM.xlsx, ApolloEcho_Dev_Kit-rev200-mar0225-PickNPlace.csv, ApolloEcho_Dev_Kit.PrjPcb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]
2025-09-11 Update: Re-arrange the Altium project groups
    [usb_serial_daughter.PrjPcb]
2025-09-12 Update: Initial release of rev210
    [ApolloEcho_Dev_Kit.PrjPcb, EM2050.SchDoc, IOs.SchDoc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]
2025-09-12 Update: Release of rev210
    [ApolloEcho_Dev_Kit-rev210-sep1225-BOM.xlsx, BOM-rev210.xlsx, EM2050.SchDoc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]
2025-10-15 Add: Schematic of ApolloEcho_Dev_Kit - Rev 2.1.0 - RAK3172.pdf
